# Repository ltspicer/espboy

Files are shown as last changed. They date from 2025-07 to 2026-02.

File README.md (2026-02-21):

# ESPboy
DIY Gameboy with ESP8266

Dieses kleine Amateurprojekt soll zeigen, was mit einem kostengünstigen ESP8266 (ESP-12E) möglich ist.

Die Materialkosten belaufen sich auf unter 20 €

ESPboy PCB Layout

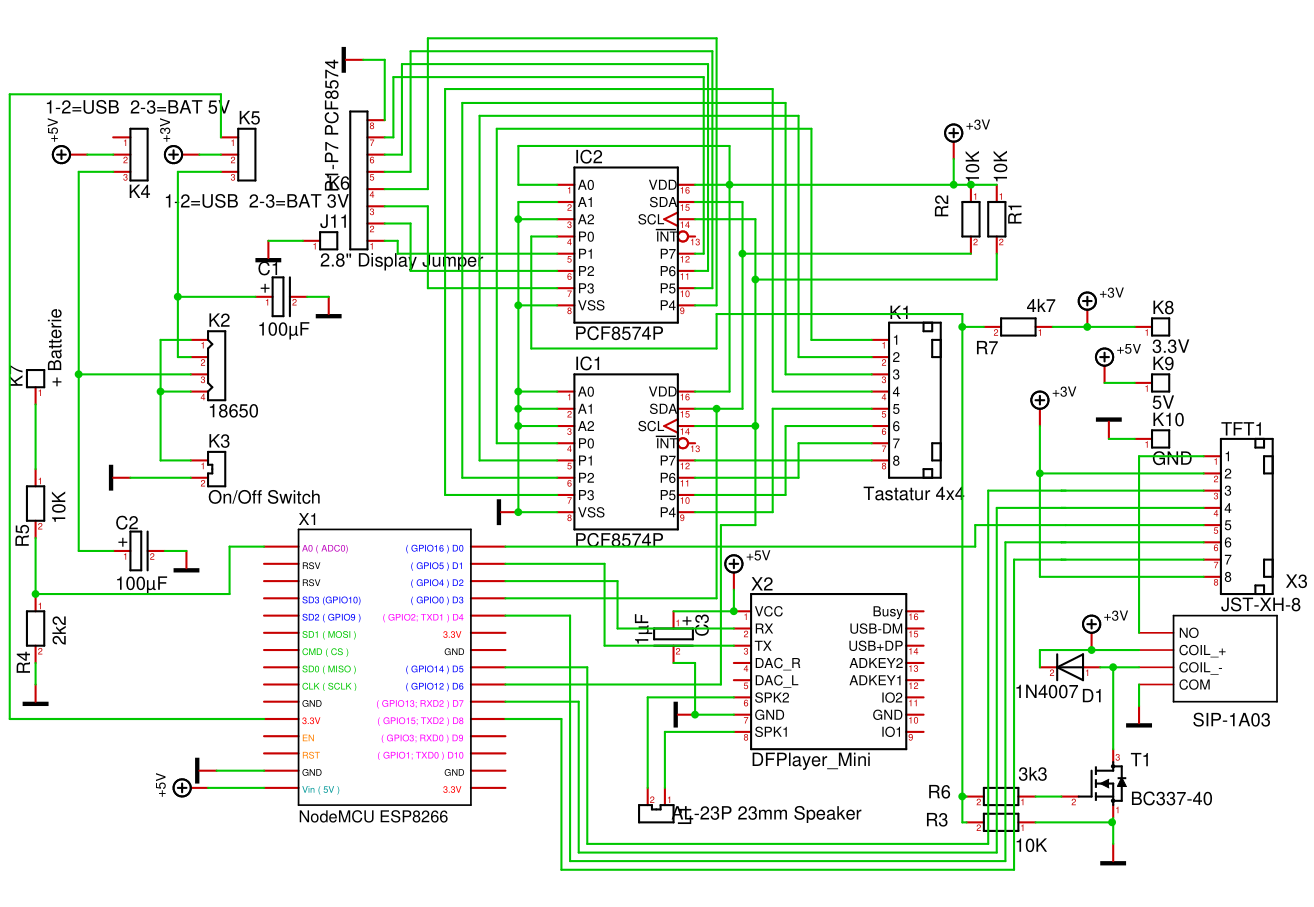
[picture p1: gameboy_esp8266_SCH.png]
ESPboy Schaltplan


------------------------
------------------------

### Enthaltene Spiele:

- Reversi
- 4 gewinnt
- Mini Mastermind
- Minesweeper
- Senso
- Snake
- Tic Tac Toe

------------------------
------------------------

### Flashen:

**Variante 1:**

Mittels Arduino IDE die ino Datei hochladen.

**Variante 2:**

Mittels **esptool.exe (Windows)** oder **esptool (Linux)** die bin Datei hochladen.

Beispiel für Windows:

**esptool.exe -vv -cd nodemcu -cb 115200 -bz 4M -cp COM7 -ca 0x00000 -cf ESPboy_V1.4.bin**

Beispiel für Linux:

**sudo ./esptool -vv -cd nodemcu -cb 115200 -bz 4M -cp /dev/ttyUSB0 -ca 0x00000 -cf ESPboy_V1.4.bin**

**Port** ( /dev/ttyUSB0 bzw COM7 ) und **bin** ( ESPboy_V1.4.bin ) ggf. **anpassen**.

------------------------
------------------------

Micro SD Karte mit **FAT32** formatieren.

mp3 Dateien im Verzeichnis **content_for_sdcard** in den Root (ohne Verzeichnis) der SD Karte kopieren (Dateien 0001 bis 0004 **einzeln** kopieren. 
Der Rest kann dann gemeinsam darauf geschoben werden). 
Dies beschleunigt den Zugriff auf die ersten 4 mp3 Dateien (wichtig für das Spiel Senso).

1 Stück Dupond Draht am Akku+ beim Akkuhalter anlöten (wird am PCB Pin **+ Batterie** angeschlossen).

1 Stück JST XH 4p Kabelsatz am Akkuhalter anlöten (GND, 3V, 5V).

2 Stück JST XH 8p Kabelsatz je an Tastatur und Display anlöten.

2 Stück JST XH 2p Kabelsatz je an Schalter und Lautsprecher anlöten.

Bei den 4 und 8-poligen JST XH Kabelsätzen beim Anlöten auf die Richtung achten (Pin 1 auf der richtigen Seite)!

Für ESP8266 und DF_Player_mini einen Pinheader weiblich 1-reihig verwenden (quasi als Sockel).

**ESPboy_V1.4.ino** mittels Arduino IDE auf den ESP8266 flashen.

Stückliste ist in der Datei **parts_list.txt** zu finden.

Im Verzeichnis **gehaeuse** sind die 2 stl Dateien für den 3D Druck.

Im Verzeichnis **XGerber_v1.4** sind die Gerber Dateien um das PCB zu erstellen.

Die Datei **gameboy_esp8266.T3001** kann mit **Target3001!** geöffnet werden (rein informativ).

Jumper K4 kann normalerweise auf 2-3 gesetzt werden.

Jumper K5 kann normalerweise auf 1-2 gesetzt werden.

------------------------
------------------------

## Changelog

### V2.3 (2026-01-11)
- Draw query inserted in 4 gewinnt

### V2.2 (2026-01-11)
- AI for Reversi and 4gewinnt much better
- Level settings over GUI for Reversi and 4gewinnt

### V2.1 (2026-01-10)
- Dummy version. Because bug in versions < 2.0 can't handle V2.0

### V2.0 (2026-01-10)
- Tic Tac Toe added

### V1.9 (2026-01-08)
- Pin7 for jumper added. Now is pin1 or pin7 supported

### V1.8 (2025-12-29)
- Game info display standardized

### V1.7 (2025-12-28)
- Snake game added

### V1.6 (2025-12-23)
- 1.8 or 2.8 inch display support

### V1.5 (2025-12-13)
- View changelog added

### V1.4 (2025-12-13)
- Over-the-Air (OTA) Update added

### V1.3 (2025-12-12)
- Improved button operation
- Minesweeper runs more smoothly

### V1.2 (2025-07-19)
- Reversi
- 4 gewinnt
- Mini Mastermind
- Minesweeper
- Senso
- Update info

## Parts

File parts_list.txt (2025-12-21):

1   nodeMCU ESP8266 ESP-12E CP2102 ( https://de.aliexpress.com/item/1005007175904162.html )
2   PCF8574P DIP16 IC
1   DF Player mini ( https://de.aliexpress.com/item/1005006027775709.html )
1   Tastatur 4x4 Matrix ( https://de.aliexpress.com/item/4000873237364.html )
1   TFT Display 1.8 Zoll 128x160 OLED ST7735 ( https://de.aliexpress.com/item/1005006691147140.html )
  oder
1   TFT Display 2.8 Zoll 240x320 OLED ST7739 ( https://de.aliexpress.com/item/1005007314570805.html )
1   Lautsprecher 8Ohm, 0.5W 23mm ( https://de.aliexpress.com/item/1005006344913948.html )
1   Ein/Aus Schalter 2 Pin ( https://de.aliexpress.com/item/1005006332969902.html )
1   1x18650 Halterung mit Ladebuchse (mini USB) und 3.3V & 5V Ausgang ( https://de.aliexpress.com/item/1005001829484812.html )
1   18650 Li-Ion Akku
2   2 Pol JST XH 2.54 Stecker/Buchse Set 20cm ( https://de.aliexpress.com/item/1005007460897865.html )
2   8 Pol JST XH 2.54 Stecker/Buchse Set 20cm ( https://de.aliexpress.com/item/1005007460897865.html )
1   4 Pol JST XH 2.54 Stecker/Buchse Set 20cm ( https://de.aliexpress.com/item/1005007460897865.html )
10  Senkkopf Blechschraube 2.6x6mm ( https://de.aliexpress.com/item/1005008358227112.html )
2   IC Sockel DIP16
2   Pinheader 40p weiblich 1-reihig zuschneidbar ( https://de.aliexpress.com/item/1005007235591794.html )
1   Pinheader mänlich 1-reihig zuschneidbar (für einzelne Testpins und Jumper-Basis)
1   BC337-40 (für Auto-Power-Off Funktion)
1   SIP-1A03 Reed-Relais 3V (für Auto-Power-Off Funktion)
2   Elko 100µF 16V (darf abweichen)
1   Elko 1µF 16V (darf abweichen)
4   10k Widerstand
1   2k2 Widerstand
1   4k7 Widerstand
1   3k3 Widerstand
1   Dupond Draht 20cm einseitig weiblich (für + Pol Akkuabgriff zu ESP-ADC0)
3   2p Jumper ( https://de.aliexpress.com/item/32892743148.html )
1   microSD Karte (mindestens 32MB)
1   Diode 1N4007 oder ähnlich (lediglich Freilaufdiode)

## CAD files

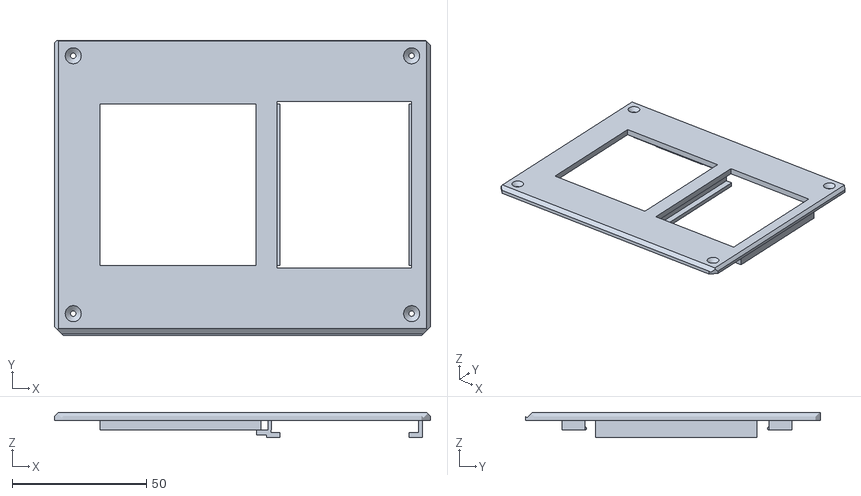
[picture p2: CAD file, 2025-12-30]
gehaeuse/Deckel_2.8_ Display.stl
140.0 x 110.0 x 9.40

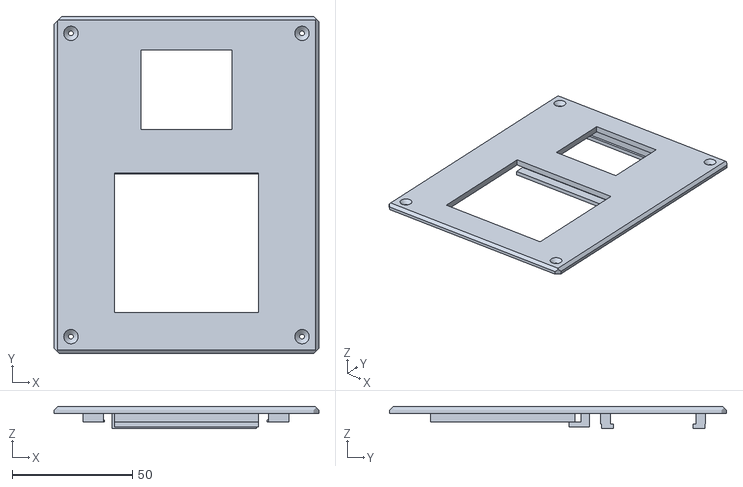
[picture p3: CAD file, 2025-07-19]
gehaeuse/Deckel.stl
110.0 x 140.0 x 9.20

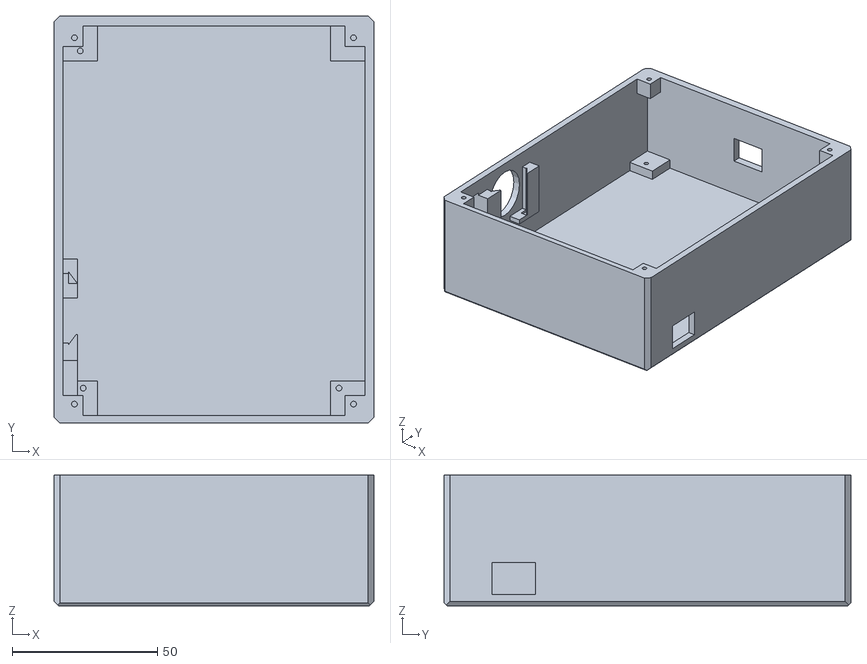
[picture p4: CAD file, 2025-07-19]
gehaeuse/Gehaeuse.stl
110.0 x 140.0 x 45.0

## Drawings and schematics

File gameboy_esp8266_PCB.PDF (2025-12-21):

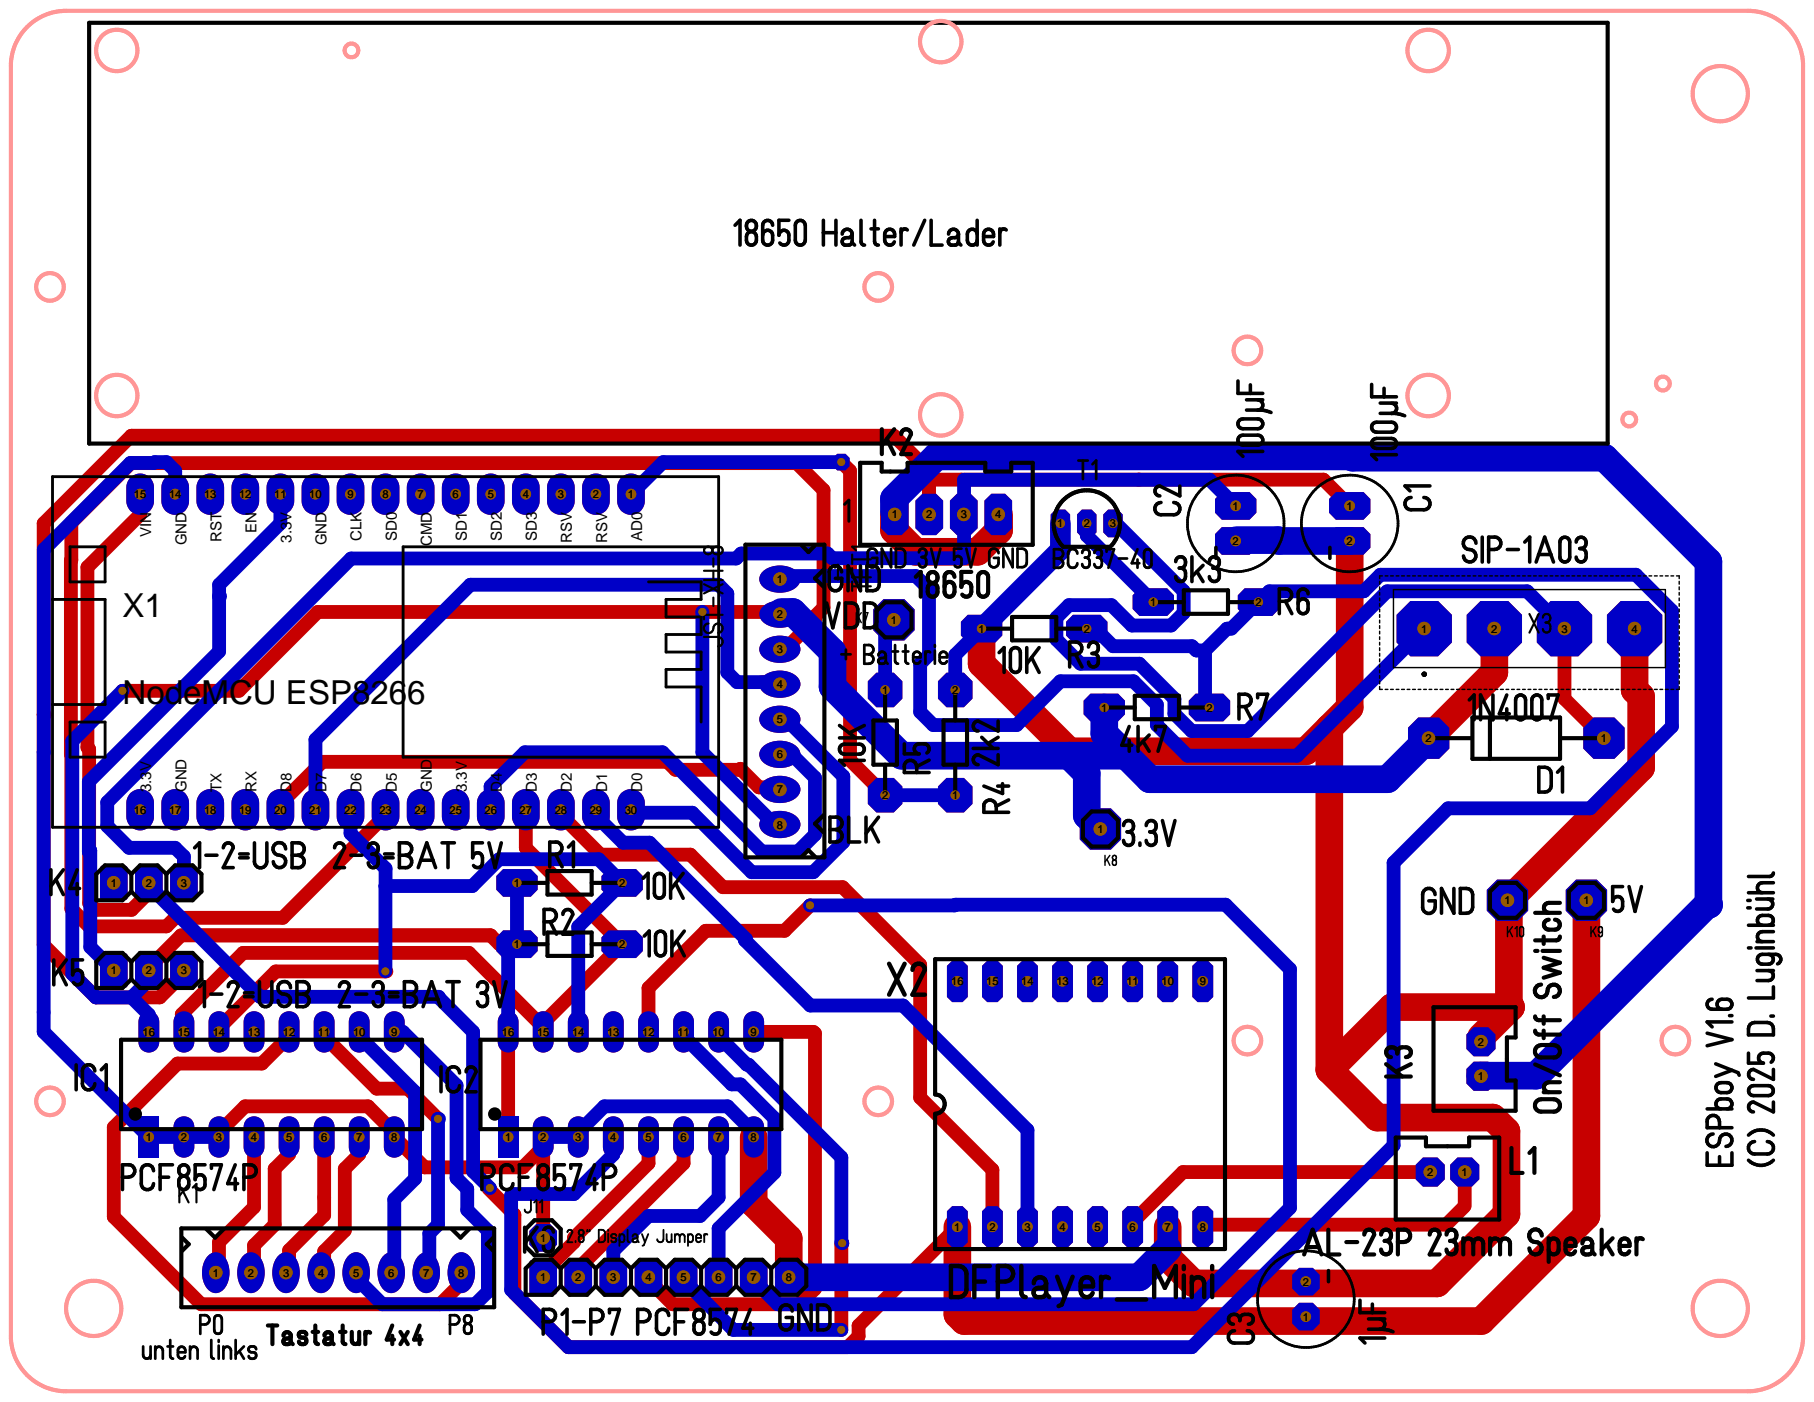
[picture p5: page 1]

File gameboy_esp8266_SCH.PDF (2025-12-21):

J11

# K6P¹⁻P⁷ PCF8574

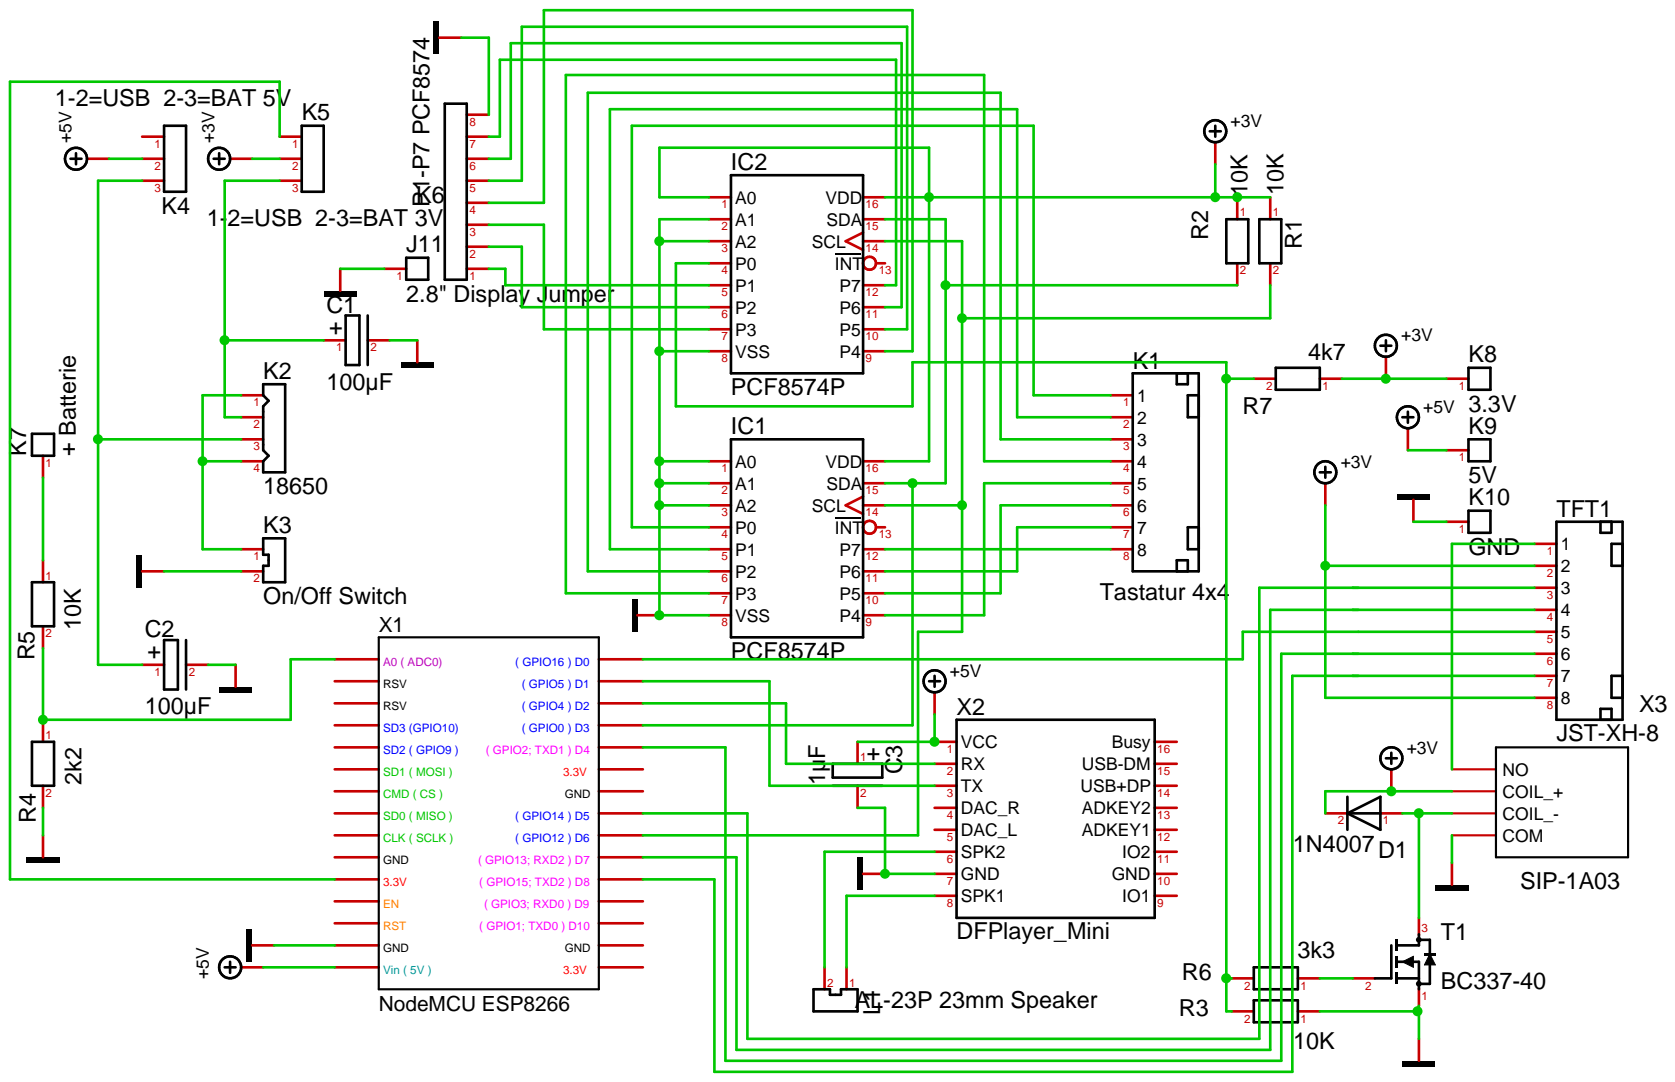
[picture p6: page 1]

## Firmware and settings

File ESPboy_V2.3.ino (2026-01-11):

///////////////////////////
//  ESPboy Taschenspiel  //
// (C) 2025 D. Luginbühl //
//  www.ltspiceusers.ch  //
///////////////////////////

bool inversDisplayJumper = false; // For testing without set/remove jumper

#define D0 16
#define D1 5
#define D2 4
#define D3 0
#define D4 2
#define D5 14
#define D6 12
#define D7 13
#define D8 15

#include <Wire.h>
#include <SPI.h>
#include <Adafruit_GFX.h>
#include <Adafruit_ST7735.h>
#include <Adafruit_ST7789.h>
#include <LittleFS.h>
#include <ESP8266WiFi.h>
#include <Updater.h>
#include <PCF8574.h>
#include "Arduino.h"
#include "DFRobotDFPlayerMini.h"
#include <SoftwareSerial.h>
#include <iostream>
#include <vector>
#include <limits.h>

// Version
const String VERSION = "V2.3";

// Aliase
#define D0 16  // D0 alias für GPIO16
#define D8 15  // D8 alias für GPIO15
#define D4 2   // D4 alias für GPIO2

// SPI-Pins für Display
#define TFT_CS D8
#define TFT_RST D0  // -1 falls nicht angeschlossen
#define TFT_DC D4

// PCF8574 für Tastatur (I2C-Adresse: 0x20)
#define PCF8574_ADDR_1 0x20
// PCF8574 für Auto-Power-Off (I2C-Adresse: 0x21)
#define PCF8574_ADDR_2 0x21

// Instanzen für die zwei PCF8574 Expander
PCF8574 pcf1(PCF8574_ADDR_1);  // Erster Expander
PCF8574 pcf2(PCF8574_ADDR_2);  // Zweiter Expander

// ST7735 Display initialisieren
Adafruit_ST7735 tft7735 = Adafruit_ST7735(TFT_CS, TFT_DC, TFT_RST);
Adafruit_ST7789 tft7789 = Adafruit_ST7789(TFT_CS, TFT_DC, TFT_RST);
Adafruit_GFX* tft = nullptr;

// Displaygröße
uint16_t TFT_WIDTH = 0;
uint16_t TFT_HEIGHT = 0;
bool smallDisplay = true;

// Spielfeld-Parameter
byte radius = 0;
uint16_t xStart = 0;
uint16_t yStart = 0;
uint16_t xEnd = 0;
uint16_t yEnd = 0;

uint8_t scale = 1;

byte SPALTEN = 7;
byte ZEILEN = 6;

uint16_t xStep = 0;
byte yStep = 0;

// Hi-Score return Werte
struct Hiscore {
  String name;
  int winner;
  int looser;
};

struct Zug {
  int x, y;
};

void initDisplay(bool smallDisplay) {
  if (smallDisplay) {
    tft = &tft7735;
    tft7735.initR(INITR_BLACKTAB);
    tft7735.setRotation(1);

    TFT_WIDTH = 128;
    TFT_HEIGHT = 160;

    radius = 7;
    xStart = 11;
    yStart = 19;
    xEnd = 143;
    yEnd = 99;

    scale = 1;

  } else {
    tft = &tft7789;
    tft7789.init(240, 320);
    tft->invertDisplay(false);
    tft7789.setRotation(3);

    TFT_WIDTH = 240;
    TFT_HEIGHT = 320;

    radius = 14;
    xStart = 22;
    yStart = 38;
    xEnd = 286;
    yEnd = 198;

    scale = 2;
  }
  xStep = (xEnd - xStart) / (SPALTEN - 1);
  yStep = (yEnd - yStart) / (ZEILEN - 1);
  Wire.begin(D3, D6);  // SDA = D3 (GPIO0), SCL = D6 (GPIO12) erneut setzen
}

// FTP
String ssid = "";
String passwd = "";
const char* ftp_server = "espboy.istmein.de";
const int ftp_port = 4321;
const char* ftp_user = "espboy";
const char* ftp_pass = "esp8266";
String loadVersionFromLittleFS();
String infoFile = "";
bool newVersionAvailable = false;
float newVersion = 0.00;
float version = 0.00;
WiFiClient client;  // Globale Variable für die FTP-Steuerverbindung

// Symbole
// 8x8 Pfeil nach links
const byte backspaceBitmap[] PROGMEM = {
  0b00000000,
  0b00100000,
  0b01000000,
  0b11111111,
  0b01000000,
  0b00100000,
  0b00000000,
  0b00000000
};

// 8x8 Pfeil nach rechts
const byte rightBitmap[] PROGMEM = {
  0b00000000,
  0b00000100,
  0b00000010,
  0b11111111,
  0b00000010,
  0b00000100,
  0b00000000,
  0b00000000
};

// 8x8 Pfeil nach unten
const byte downBitmap[] PROGMEM = {
  0b00010000,
  0b00010000,
  0b00010000,
  0b00010000,
  0b10010010,
  0b01010100,
  0b00111000,
  0b00010000
};

// 8x8 Pfeil nach unten
const byte upBitmap[] PROGMEM = {
  0b00010000,
  0b00111000,
  0b01010100,
  0b10010010,
  0b00010000,
  0b00010000,
  0b00010000,
  0b00010000
};

// 8x8 RETURN-Pfeil
const byte returnBitmap[] PROGMEM = {
  0b00000000,
  0b00100001,
  0b01000001,
  0b11111111,
  0b01000000,
  0b00100000,
  0b00000000,
  0b00000000
};

// 10x10 Taste 0
const byte button0Bitmap[] PROGMEM = {
  0b11111111, 0b11000000,
  0b10000000, 0b01000000,
  0b10011110, 0b01000000,
  0b10100001, 0b01000000,
  0b10100001, 0b01000000,
  0b10100001, 0b01000000,
  0b10100001, 0b01000000,
  0b10011110, 0b01000000,
  0b10000000, 0b01000000,
  0b11111111, 0b11000000
};

// 10x10 Taste 1
const byte button1Bitmap[] PROGMEM = {
  0b11111111, 0b11000000,
  0b10000000, 0b01000000,
  0b10000010, 0b01000000,
  0b10000110, 0b01000000,
  0b10001010, 0b01000000,
  0b10000010, 0b01000000,
  0b10000010, 0b01000000,
  0b10000010, 0b01000000,
  0b10000000, 0b01000000,
  0b11111111, 0b11000000
};

// 10x10 Taste 2 - Korrigierte Bitmap
const byte button2Bitmap[] PROGMEM = {
  0b11111111, 0b11000000,
  0b10000000, 0b01000000,
  0b10011110, 0b01000000,
  0b10100001, 0b01000000,
  0b10000011, 0b01000000,
  0b10001100, 0b01000000,
  0b10110000, 0b01000000,
  0b10111111, 0b01000000,
  0b10000000, 0b01000000,
  0b11111111, 0b11000000
};

// 10x10 Taste 3
const byte button3Bitmap[] PROGMEM = {
  0b11111111, 0b11000000,
  0b10000000, 0b01000000,
  0b10111110, 0b01000000,
  0b10000001, 0b01000000,
  0b10011110, 0b01000000,
  0b10000001, 0b01000000,
  0b10000001, 0b01000000,
  0b10111110, 0b01000000,
  0b10000000, 0b01000000,
  0b11111111, 0b11000000
};

// 10x10 Taste 4
const byte button4Bitmap[] PROGMEM = {
  0b11111111, 0b11000000,
  0b10000000, 0b01000000,
  0b10000010, 0b01000000,
  0b10100010, 0b01000000,
  0b10100010, 0b01000000,
  0b10111111, 0b01000000,
  0b10000010, 0b01000000,
  0b10000010, 0b01000000,
  0b10000000, 0b01000000,
  0b11111111, 0b11000000
};

// 10x10 Taste 5
const byte button5Bitmap[] PROGMEM = {
  0b11111111, 0b11000000,
  0b10000000, 0b01000000,
  0b10111110, 0b01000000,
  0b10100000, 0b01000000,
  0b10111110, 0b01000000,
  0b10000001, 0b01000000,
  0b10000001, 0b01000000,
  0b10111110, 0b01000000,
  0b10000000, 0b01000000,
  0b11111111, 0b11000000
};

// 10x10 Taste 6
const byte button6Bitmap[] PROGMEM = {
  0b11111111, 0b11000000,
  0b10000000, 0b01000000,
  0b10011100, 0b01000000,
  0b10100000, 0b01000000,
  0b10111110, 0b01000000,
  0b10100001, 0b01000000,
  0b10100001, 0b01000000,
  0b10011110, 0b01000000,
  0b10000000, 0b01000000,
  0b11111111, 0b11000000
};

// 10x10 Taste 7
const byte button7Bitmap[] PROGMEM = {
  0b11111111, 0b11000000,
  0b10000000, 0b01000000,
  0b10111111, 0b01000000,
  0b10000010, 0b01000000,
  0b10000100, 0b01000000,
  0b10001000, 0b01000000,
  0b10010000, 0b01000000,
  0b10100000, 0b01000000,
  0b10000000, 0b01000000,
  0b11111111, 0b11000000
};

// 10x10 Taste 8
const byte button8Bitmap[] PROGMEM = {
  0b11111111, 0b11000000,
  0b10000000, 0b01000000,
  0b10011110, 0b01000000,
  0b10100001, 0b01000000,
  0b10011110, 0b01000000,
  0b10100001, 0b01000000,
  0b10100001, 0b01000000,
  0b10011110, 0b01000000,
  0b10000000, 0b01000000,
  0b11111111, 0b11000000
};

// 10x10 Taste 9
const byte button9Bitmap[] PROGMEM = {
  0b11111111, 0b11000000,
  0b10000000, 0b01000000,
  0b10011110, 0b01000000,
  0b10100001, 0b01000000,
  0b10011111, 0b01000000,
  0b10000001, 0b01000000,
  0b10000010, 0b01000000,
  0b10011100, 0b01000000,
  0b10000000, 0b01000000,
  0b11111111, 0b11000000
};

// 10x10 Taste A
const byte buttonABitmap[] PROGMEM = {
  0b11111111, 0b11000000,
  0b10000000, 0b01000000,
  0b10011110, 0b01000000,
  0b10100001, 0b01000000,
  0b10111111, 0b01000000,
  0b10100001, 0b01000000,
  0b10100001, 0b01000000,
  0b10100001, 0b01000000,
  0b10000000, 0b01000000,
  0b11111111, 0b11000000
};

// 10x10 Taste B
const byte buttonBBitmap[] PROGMEM = {
  0b11111111, 0b11000000,
  0b10000000, 0b01000000,
  0b10111110, 0b01000000,
  0b10100001, 0b01000000,
  0b10111110, 0b01000000,
  0b10100001, 0b01000000,
  0b10100001, 0b01000000,
  0b10111110, 0b01000000,
  0b10000000, 0b01000000,
  0b11111111, 0b11000000
};

// 10x10 Taste C
const byte buttonCBitmap[] PROGMEM = {
  0b11111111, 0b11000000,
  0b10000000, 0b01000000,
  0b10011111, 0b01000000,
  0b10100000, 0b01000000,
  0b10100000, 0b01000000,
  0b10100000, 0b01000000,
  0b10100000, 0b01000000,
  0b10011111, 0b01000000,
  0b10000000, 0b01000000,
  0b11111111, 0b11000000
};

// 10x10 Taste D
const byte buttonDBitmap[] PROGMEM = {
  0b11111111, 0b11000000,
  0b10000000, 0b01000000,
  0b10111110, 0b01000000,
  0b10100001, 0b01000000,
  0b10100001, 0b01000000,
  0b10100001, 0b01000000,
  0b10100001, 0b01000000,
  0b10111110, 0b01000000,
  0b10000000, 0b01000000,
  0b11111111, 0b11000000
};

// 10x10 Taste *
const byte buttonStarBitmap[] PROGMEM = {
  0b11111111, 0b11000000,
  0b10000000, 0b01000000,
  0b10010010, 0b01000000,
  0b10001100, 0b01000000,
  0b10111111, 0b01000000,
  0b10001100, 0b01000000,
  0b10010010, 0b01000000,
  0b10000000, 0b01000000,
  0b10000000, 0b01000000,
  0b11111111, 0b11000000
};

// 10x10 Taste #
const byte buttonHashBitmap[] PROGMEM = {
  0b11111111, 0b11000000,
  0b10000000, 0b01000000,
  0b10001010, 0b01000000,
  0b10001010, 0b01000000,
  0b10111111, 0b11000000,
  0b10001010, 0b01000000,
  0b10111111, 0b11000000,
  0b10001010, 0b01000000,
  0b10001010, 0b01000000,
  0b11111111, 0b11000000
};

// 20x20 Taste #
const byte buttonHashBitmap20x20[] PROGMEM = {
  0b11111111, 0b11111111, 0b11110000,
  0b11111111, 0b11111111, 0b11110000,
  0b11000000, 0b00000000, 0b00110000,
  0b11000010, 0b00000100, 0b00110000,
  0b11000010, 0b00000100, 0b00110000,
  0b11000010, 0b00000100, 0b00110000,
  0b11011111, 0b11111111, 0b10110000,
  0b11011111, 0b11111111, 0b10110000,
  0b11000010, 0b00000100, 0b00110000,
  0b11000010, 0b00000100, 0b00110000,
  0b11000010, 0b00000100, 0b00110000,
  0b11011111, 0b11111111, 0b10110000,
  0b11011111, 0b11111111, 0b10110000,
  0b11000010, 0b00000100, 0b00110000,
  0b11000010, 0b00000100, 0b00110000,
  0b11000010, 0b00000100, 0b00110000,
  0b11000000, 0b00000000, 0b00110000,
  0b11000000, 0b00000000, 0b00110000,
  0b11111111, 0b11111111, 0b11110000,
  0b11111111, 0b11111111, 0b11110000
};

// Allgemeine Variabeln
uint16_t bgColor = ST77XX_BLACK;
uint16_t spielerColor = ST77XX_RED;
uint16_t computerColor = ST77XX_YELLOW;
uint16_t iconColor = ST77XX_WHITE;
uint16_t textColor = ST77XX_WHITE;
const byte LEER = 0;
const byte SPIELER = 1;
const byte COMPUTER = 2;

bool spielerDran = true;  // Wechselt nach jedem Zug
// Für Akkuberechnung
const int anzahlAkkuWerte = 20;  // Anzahl der letzten Werte für den Durchschnitt
int akkuWerte[anzahlAkkuWerte];
int batterieSpannung = 240;       // Akkuspannung an A0 Variabel Init
const int akkuObererWert = 243;   // 100% Akku Wert an A0
const int akkuUntererWert = 170;  // 0% Akku Wert an A0
bool online = false;              // Wifi verbunden?

static byte backupStack[10][20][20];

byte spielfeld[20][20];

// Für Karussell
byte ziffer1, ziffer2, ziffer3;
byte messageY = 0;

// Für 4 gewinnt
byte pfeilPos = SPALTEN / 2;        // Startposition des Pfeils in der Mitte
byte vierGewinntMaxDepth = 2;       // Maximale Tiefe des Minimax
const byte order[7] = {3, 2, 4, 1, 5, 0, 6};

// Für Reversi
int xPos = 0;
int yPos = 0;

byte reversiLevel = 3;              // Maximale Tiefe des Minimax

const int richtungen[8][2] = {  // Richtungen für das Überprüfen von Flips
  { -1, -1 },
  { 0, -1 },
  { 1, -1 },
  { -1, 0 },
  { 1, 0 },
  { -1, 1 },
  { 0, 1 },
  { 1, 1 }
};

const int WEIGHT[8][8] = {
  {1000, -200,  20,  10,  10,  20, -200, 1000},
  {-200, -500,  -5,  -5,  -5,  -5, -500, -200},
  {  20,   -5,   5,   1,   1,   5,   -5,   20},
  {  10,   -5,   1,   0,   0,   1,   -5,   10},
  {  10,   -5,   1,   0,   0,   1,   -5,   10},
  {  20,   -5,   5,   1,   1,   5,   -5,   20},
  {-200, -500,  -5,  -5,  -5,  -5, -500, -200},
  {1000, -200,  20,  10,  10,  20, -200, 1000}
};

// Für Minesweeper
#define FIELD_WIDTH 10  // 10x8 Felder
#define FIELD_HEIGHT 8
uint16_t TILE_SIZE = 0;

#define ST77XX_LIGHTGREY 0xCE79   // Hellgrau
#define ST77XX_MIDGREY 0x8C71     // Mittelgrau
#define ST77XX_DARKGREY 0x52AA    // Dunkelgrau
#define ST77XX_DARKBLUE 0x0011    // Dunkelblau
#define ST77XX_DARKGREEN 0x03E0   // Dunkelgrün
#define ST77XX_WINERED 0x780F     // Weinrot
#define ST77XX_DARKRED 0x6000     // Dunkelrot
#define ST77XX_DARKYELLOW 0xA540  // Dunkelgelb

byte grid[FIELD_HEIGHT][FIELD_WIDTH];      // 0-8 = Zahl, 9 = Mine
bool revealed[FIELD_HEIGHT][FIELD_WIDTH];  // Aufgedeckte Felder
bool flagged[FIELD_HEIGHT][FIELD_WIDTH];   // Gesetze Fahnen
byte NUM_MINES = 10;

int cursorX = 0;
int cursorY = 0;
int oldCursorX = 0;
int oldCursorY = 0;

// Für Senso
#define GAME_STATUS_END 1
#define GAME_STATUS_CANCELED 3
#define GAME_STATUS_RUNNING 2
#define BUTTON_MAX_INTERVAL 4000  // Antwortzeit bis Game over
#define DELAY_INIT 800            // Geschwindigkeit (Verzögerung) Startwert
#define DELAY_MIN 300             // Geschwindigkeit (Verzögerung) Minimum (300)
#define DELAY_STEP 50             // Geschwindigkeit (Verzögerung) Verkleinerungsschritte

#define SENSO_FELD_ROT 0
#define SENSO_FELD_GELB 1
#define SENSO_FELD_GRUEN 2
#define SENSO_FELD_BLAU 3

#define SENSO_NO_PIN 255  // Keine Taste gedrückt

// --- Layout-Konstanten ---
uint16_t LOGICAL_WIDTH = 0;
uint16_t LOGICAL_HEIGHT = 0;

uint16_t BTN_SIZE = 0;
uint16_t BTN_RADIUS = 0;

uint16_t CENTER_X = 0;
uint16_t CENTER_Y = 0;

uint16_t OFFSET_X = 0;
uint16_t OFFSET_Y = 0;

uint16_t POS_ROT_X = 0;
uint16_t POS_ROT_Y = 0;

uint16_t POS_GELB_X = 0;
uint16_t POS_GELB_Y = 0;

uint16_t POS_GRUEN_X = 0;
uint16_t POS_GRUEN_Y = 0;

uint16_t POS_BLAU_X = 0;
uint16_t POS_BLAU_Y = 0;

bool isWaitingForPlayer, isColorPlayed;
byte sensoScore, sensoGameStatus, sensoSequenceIndex, pressedButton, sensoSequence[100], sensoTon[4];
int gameDelay;
unsigned long lastPlayerAction, lastButtonPressed;

void drawBitmapScaled(int16_t x, int16_t y,
                      const uint8_t* bitmap,
                      int16_t w, int16_t h,
                      uint16_t color) {
  for (int16_t j = 0; j < h; j++) {
    for (int16_t i = 0; i < w; i++) {

      uint8_t byte = pgm_read_byte(bitmap + (j * ((w + 7) / 8)) + (i / 8));
      bool pixelOn = byte & (0x80 >> (i & 7));

      if (pixelOn) {
        tft->fillRect(x + i * scale, y + j * scale, scale, scale, color);
      }
    }
  }
}

// Für Snake
#define snakesize 250
//Snake's speed between movement(miliseconds)
#define velocity 250

#define gridx 30
#define gridy 20

byte snakeBuffer[snakesize][2];
byte snakeGrid[gridy][gridx];

// Für Tic Tac Toe
const byte tttWins[8][3] = {
  {0,1,2}, {3,4,5}, {6,7,8},   // Reihen
  {0,3,6}, {1,4,7}, {2,5,8},   // Spalten
  {0,4,8}, {2,4,6}             // Diagonalen
};
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
void loop() {
  delay(500);
}

// Einstellungs-Menu
void settingsMenu() {
  displaySettingsMenu();
  delay(500);
  while (true) {
    autoPowerOff();
    char pressedKey = scanKeypad();  // Tastaturabfrage
    if (pressedKey >= '1' && pressedKey <= '9') {
      lastActivity = millis();
      auswahl = pressedKey - '0';  // Zeichen in Zahl umwandeln
      switch (auswahl) {
        case 1:
          Serial.println(F("4 gewinnt Level gewählt"));
          readNumberFromKeypad("Level", "4gewinntlevel", 2, 4, 1);
          displaySettingsMenu();
          break;
        case 2:
          Serial.println(F("Reversi Level gewählt"));
          readNumberFromKeypad("Level", "reversilevel", 3, 6, 1);
          displaySettingsMenu();
          break;
        case 3:
          Serial.println(F("Minesweeper Minen gewählt"));
          readMinesNumberFromKeypad();
          displaySettingsMenu();
          break;
        case 4:
          Serial.println(F("Hiscore löschen gewählt"));
          deleteHiscores();
          displaySettingsMenu();
          break;
        case 5:
          Serial.println(F("Volume gewählt"));
          readNumberFromKeypad("Volume", "volume", 20, 30, 0);
          displaySettingsMenu();
          break;
        case 6:
          Serial.println(F("WLAN gewählt"));
          configureWiFi();
          displaySettingsMenu();
          break;
        case 7:
          Serial.println(F("Changelog gewählt"));
          tft->fillScreen(bgColor);
          tft->setCursor(0, 0);
          displayInfoFile(infoFile, smallDisplay ? 16 : 30);
          delay(500);
          char key;
          while (true) {
            autoPowerOff();
            key = scanKeypad();
            if (key != '\0') {
              break;
            }
          }
          displaySettingsMenu();
          break;
      }
    } else if (pressedKey == 'A') {
      Serial.println(F("Abbruch gewählt"));
      return;
    }
  }
}

// Funktion für Auto-Power-Off
void autoPowerOff() {
  int batterieSpannung = addValue();  // Neuen Wert zur Warteschlange hinzufügen
  //Serial.print(F("Analog Eingang: "));
  //Serial.println(batterieSpannung);
  if (millis() - lastActivity >= SLEEP_TIME) {
    Serial.println(F("Keine Aktivität – Gehe in den Deep Sleep-Modus..."));
    myDFPlayer.sleep();
    delay(1000);
    pcf2.write(0, LOW);  // Display ausschalten
    delay(1000);
    ESP.deepSleep(0);  // Unendlich schlafen
  }
}

// Fügt einen neuen Wert hinzu und entfernt den ältesten
int addValue() {
  int newValue = analogRead(A0);  // Neuen Sensorwert einlesen
  if (newValue < akkuUntererWert) {
    newValue = akkuUntererWert;
  }
  if (newValue > akkuObererWert) {
    newValue = akkuObererWert;
  }
  // Alle Werte nach links verschieben (ältester Wert fällt raus)
  for (int i = 0; i < anzahlAkkuWerte - 1; i++) {
    akkuWerte[i] = akkuWerte[i + 1];
  }
  akkuWerte[anzahlAkkuWerte - 1] = newValue;  // Neuen Wert an letzter Position speichern
  return newValue;
}

// Berechnet den Durchschnitt der gespeicherten Werte
int berechneDurchschnitt() {
  int sum = 0;
  for (int i = 0; i < anzahlAkkuWerte; i++) {
    sum += akkuWerte[i];
  }

  int durchschnitt = sum / anzahlAkkuWerte;

  // Negative Werte verhindern
  if (durchschnitt < 0) return 0;

  return durchschnitt;
}

int berechneProzentAkku() {
  static int letzterProzentWert = -1;
  static int untereSchwelle = -1;
  static int obereSchwelle = -1;

  int akkuDurchschnittsWert = berechneDurchschnitt();
  const int skala = akkuObererWert - akkuUntererWert;
  int analogWertBasisNull = akkuDurchschnittsWert - akkuUntererWert;
  int prozentWert = (analogWertBasisNull * 100) / skala;

  // Beim ersten Durchlauf Initialisierung
  if (letzterProzentWert == -1) {
    letzterProzentWert = (prozentWert / 5) * 5;  // Initial auf 5er-Wert setzen
    untereSchwelle = letzterProzentWert - 5;     // Hysterese nach unten
    obereSchwelle = letzterProzentWert + 5;      // Hysterese nach oben
  }

  // **Hysterese: Wechsel nur bei ±5 % Differenz**
  if (prozentWert >= obereSchwelle) {
    letzterProzentWert = ((prozentWert + 2) / 5) * 5;  // Neu runden
    untereSchwelle = letzterProzentWert - 5;           // Neue untere Grenze
    obereSchwelle = letzterProzentWert + 5;            // Neue obere Grenze
  } else if (prozentWert <= untereSchwelle) {
    letzterProzentWert = ((prozentWert + 2) / 5) * 5;
    untereSchwelle = letzterProzentWert - 5;
    obereSchwelle = letzterProzentWert + 5;
  }
  return letzterProzentWert;
}

//////////////////////////////////
// Funktionen für Tastaturabfragen
//////////////////////////////////

// Funktion zur Tastatur-Abfrage mit Zeichenfilterung
char scanKeypad() {
  for (byte row = 0; row < 4; row++) {
    // Setze die aktuelle Reihe (P0 bis P3) auf LOW, die anderen auf HIGH
    for (byte pin = 0; pin < 4; pin++) {
      pcf1.write(pin, HIGH);
    }
    pcf1.write(row, LOW);

    // Lese die Spalten (P4 bis P7) als Eingänge vom ersten PCF8574
    byte inputData = 0;
    for (byte col = 4; col < 8; col++) {
      inputData |= pcf1.read(col) << (col - 4);  // Lese die Spalten P4 bis P7
    }

    // Überprüfe, ob einer der Pins auf LOW gezogen wurde
    for (byte col = 0; col < 4; col++) {
      if (!(inputData & (1 << col))) {  // Wenn der Pin auf LOW gezogen wurde
        lastActivity = millis();        // Autopower-off verzögern
        char key = keys[row][col];      // Gelesene Taste

        // Prüfen, ob das Zeichen erlaubt ist
        for (byte i = 0; i < sizeof(allowedChars) - 1; i++) {
          if (key == allowedChars[i]) {
            return key;  // Nur gültige Zeichen zurückgeben
          }
        }
      }
    }
    delay(5);  // Kurze Verzögerung, bevor zur nächsten Reihe gewechselt wird
  }
  return 0;  // Keine Taste gedrückt oder ungültige Taste
}

// User Werteingabe
void readNumberFromKeypad(String titel, String filename, int standardWert, int maxInput, int minInput) {
  byte value = loadValueFromLittleFS(filename, standardWert);
  displayKeyInput(titel, value);
  char key;
  while (true) {
    key = scanKeypad();
    autoPowerOff();
    if (key == 'A') {
      saveValueToLittleFS(filename, String(value));  // Speichern, wenn Eingabe abgeschlossen
      break;
    }
    if (key == '*') {
      value = max(minInput, value - 1);  // Decrement
      displayKeyInput(titel, value);
      myDFPlayer.volume(value);
    } else if (key == 'D') {
      value = min(maxInput, value + 1);  // Increment
      displayKeyInput(titel, value);
      myDFPlayer.volume(value);
    }
    delay(200);  // Entprellung
  }
}

// Minesweeper Minen eingeben
void readMinesNumberFromKeypad() {
  int value = loadValueFromLittleFS("mines", 10);
  displayMines(value);
  char key;
  while (true) {
    key = scanKeypad();  // Taste einlesen
    autoPowerOff();      // Power-Off prüfen

    if (key == 'A') {
      if (value > 0 && value < 80) {
        saveValueToLittleFS("mines", String(value));  // Speichern, wenn Eingabe abgeschlossen
        break;
      } else {
        Serial.println(F("Nur Werte von 1 bis 79 erlaubt!"));
      }
    } else if (key >= '0' && key <= '9') {
      Serial.print(F("Eingabe: "));
      Serial.println(key);
      value = value * 10;           // Verschiebe nach links und füge Ziffer rechts hinzu
      value = value % 100;          // Hunderter Stelle abschneiden
      value = value + (key - '0');  // Aktuelle Ziffer hinzufügen
      displayMines(value);
    }
    delay(200);  // Entprellung
  }
}
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

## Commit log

2025-07-19 Add files via upload
    Gehäuse (stl), Gerber, Stückliste, PCB & Schaltplan Bilder
    [Deckel.stl, Gehaeuse.stl]
2025-07-19 Add files via upload
    PCB V1.4
2025-12-21 Add files via upload
    V1.6
    - Jumper for display selection added on PCB (future version)
2026-01-11 Add files via upload
    V2.3
    - Draw query inserted in 4 gewinnt
2026-02-21 Update schematic image format in README
